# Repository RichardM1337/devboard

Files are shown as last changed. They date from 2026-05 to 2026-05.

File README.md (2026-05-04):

# Devboard
This is my first devboard. It's my introduction to more advanced concepts

This was probably one of the hardest projects I have done ever. The wiring made me want to cry but we were able to get through it. Looking back, I think I've came very far and I'm really happy about my progress.

# PCB
The devboard PCB was made entirely on KiCAD

- Schematic
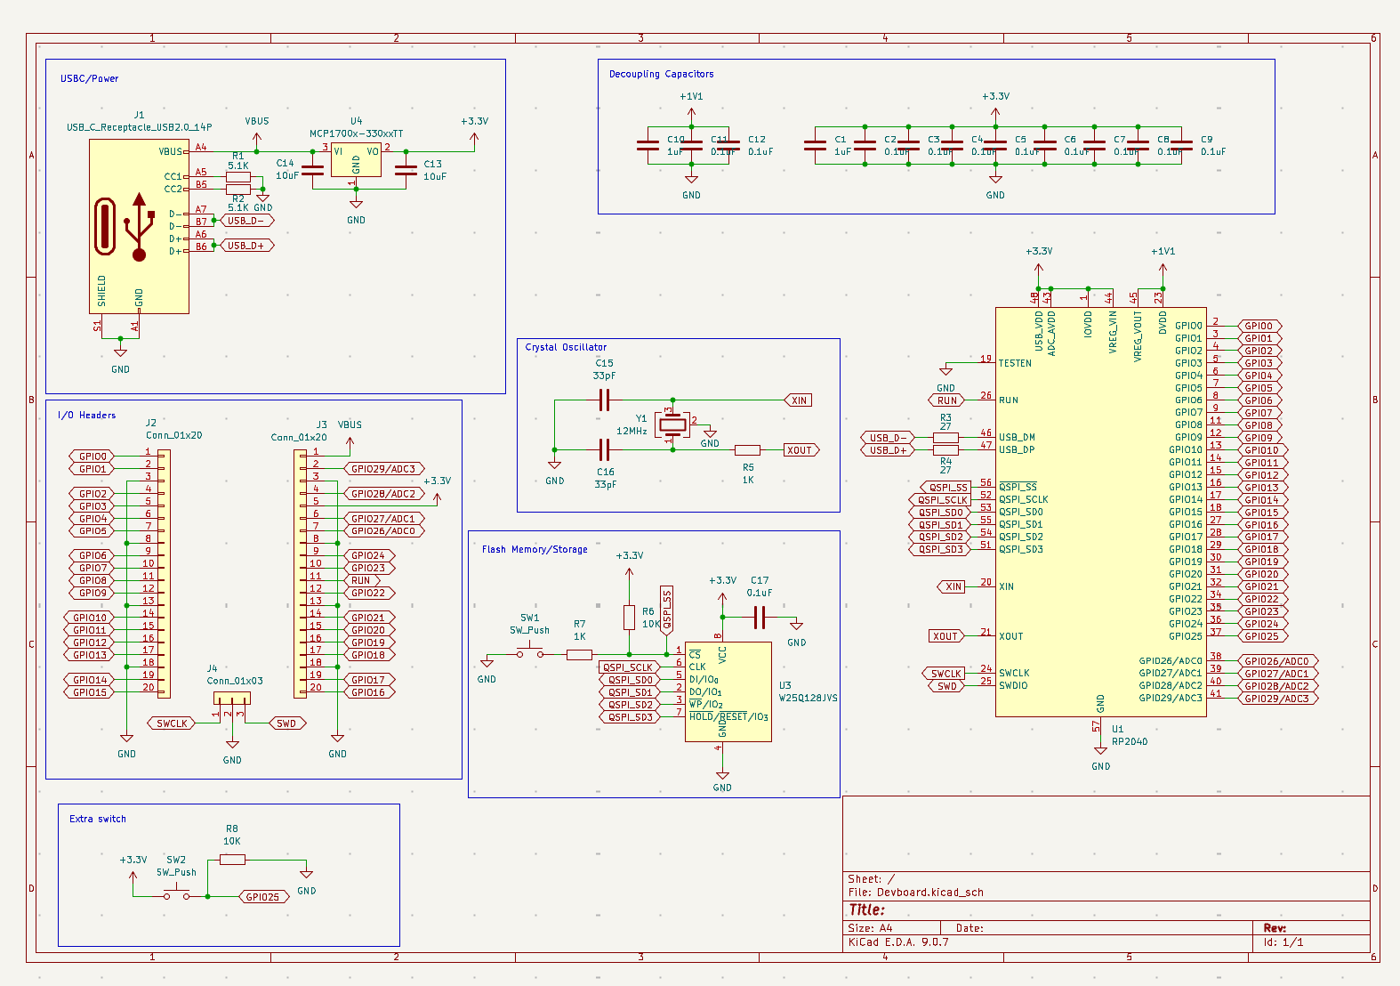
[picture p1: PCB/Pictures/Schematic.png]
Schematic
- 
- PCB Design
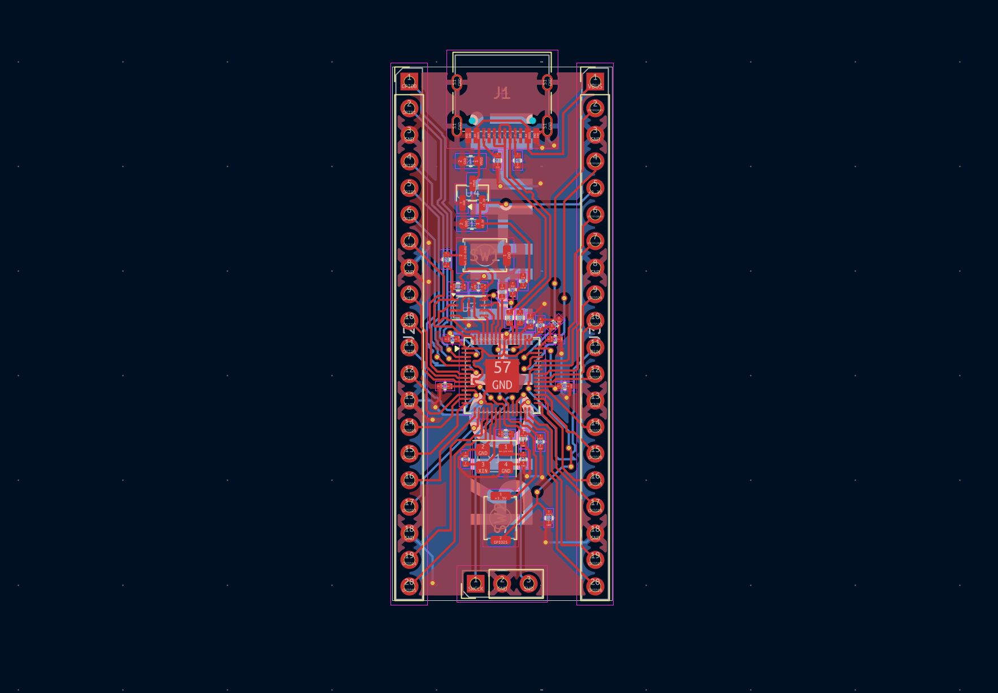
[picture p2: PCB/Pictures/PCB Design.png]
PCB Design
- 

# 3D Model
This 3d model of the devboard was made within the 3d viewer in KiCAD

- Front
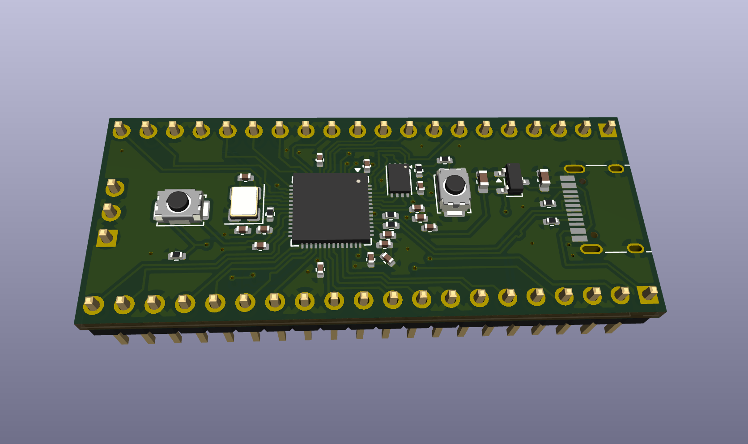
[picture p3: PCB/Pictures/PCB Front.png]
PCB Front
- 
- Back
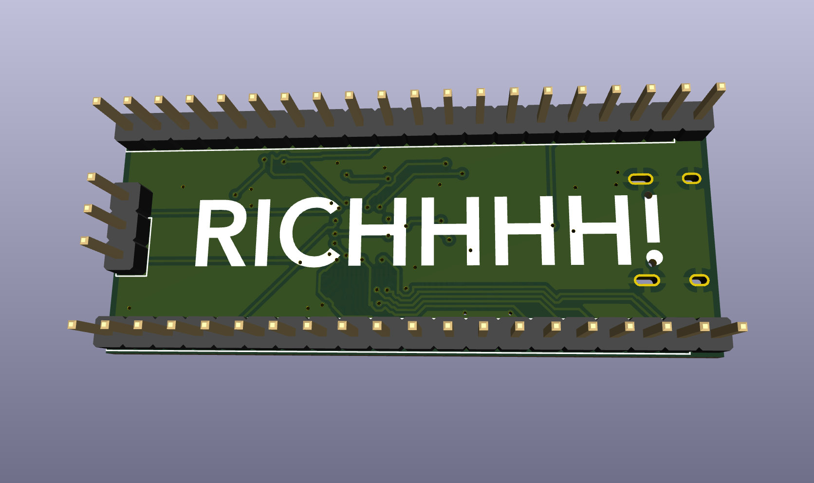
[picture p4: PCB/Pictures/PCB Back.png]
PCB Back
- 

# BOM Bill of Materials

| Quantity | Comment | Designator | Footprint | Link |
|---|---|---|---|---|
| 11 | 0.1uF | C2-9, C11, C12, C17 | C_0402_1005Metric | https://www.lcsc.com/product-detail/C1525.html |
| 2 | 5.1K | R1, R2 | R_0402_1005Metric | https://www.lcsc.com/product-detail/C25905.html |
| 1 | SW_Push | SW1, SW2 | SW_Push_SPST_NO_Alps_SKRK | https://www.lcsc.com/product-detail/C720477.html |
| 2 | 10uF | C13, C14 | C_0603_1608Metric | https://www.lcsc.com/product-detail/C19702.html |
| 2 | 33pF | C15, C16 | C_0402_1005Metric | https://www.lcsc.com/product-detail/C107047.html |
| 2 | 1K | R5, R7 | R_0402_1005Metric | https://www.lcsc.com/product-detail/C11702.html |
| 2 | 10K | R6, R8 | R_0402_1005Metric | https://www.lcsc.com/product-detail/C60490.html |
| 1 | W25Q128JVS | U3 | Winbond_USON-8-1EP_3x2mm_P0.5mm_EP0.2x1.6mm | https://www.lcsc.com/product-detail/C2456208.html  |
| 2 | Conn_01x20 | J2, J3 | PinHeader_1x20_P2.54mm_Vertical | https://www.lcsc.com/product-detail/C42431804.html |
| 1 | Conn_01x03 | J4 | PinHeader_1x03_P2.54mm_Vertical | https://www.lcsc.com/product-detail/C32713269.html |
| 1 | MCP1700x-330xxTT | U4 | SOT-23 | https://www.lcsc.com/product-detail/C39051.html |
| 1 | 12MHz | Y1 | Crystal_SMD_3225-4Pin_3.2x2.5mm | https://www.lcsc.com/product-detail/C9002.html |
| 2 | 27 | R3, R4 | R_0402_1005Metric | https://www.lcsc.com/product-detail/C25100.html |
| 2 | 1uF | C1, C10 | C_0402_1005Metric | https://www.lcsc.com/product-detail/C29266.html |
| 1 | USB_C_Receptacle_USB2.0_14P | J1 | USB_C_Receptacle_HRO_TYPE-C-31-M-12 | https://www.lcsc.com/product-detail/C165948.html |
| 1 | RP2040 | U1 | QFN-56-1EP_7x7mm_P0.4mm_EP3.2x3.2mm | https://www.lcsc.com/product-detail/C2040.html |
| PCBA Estimated Price| $50.84

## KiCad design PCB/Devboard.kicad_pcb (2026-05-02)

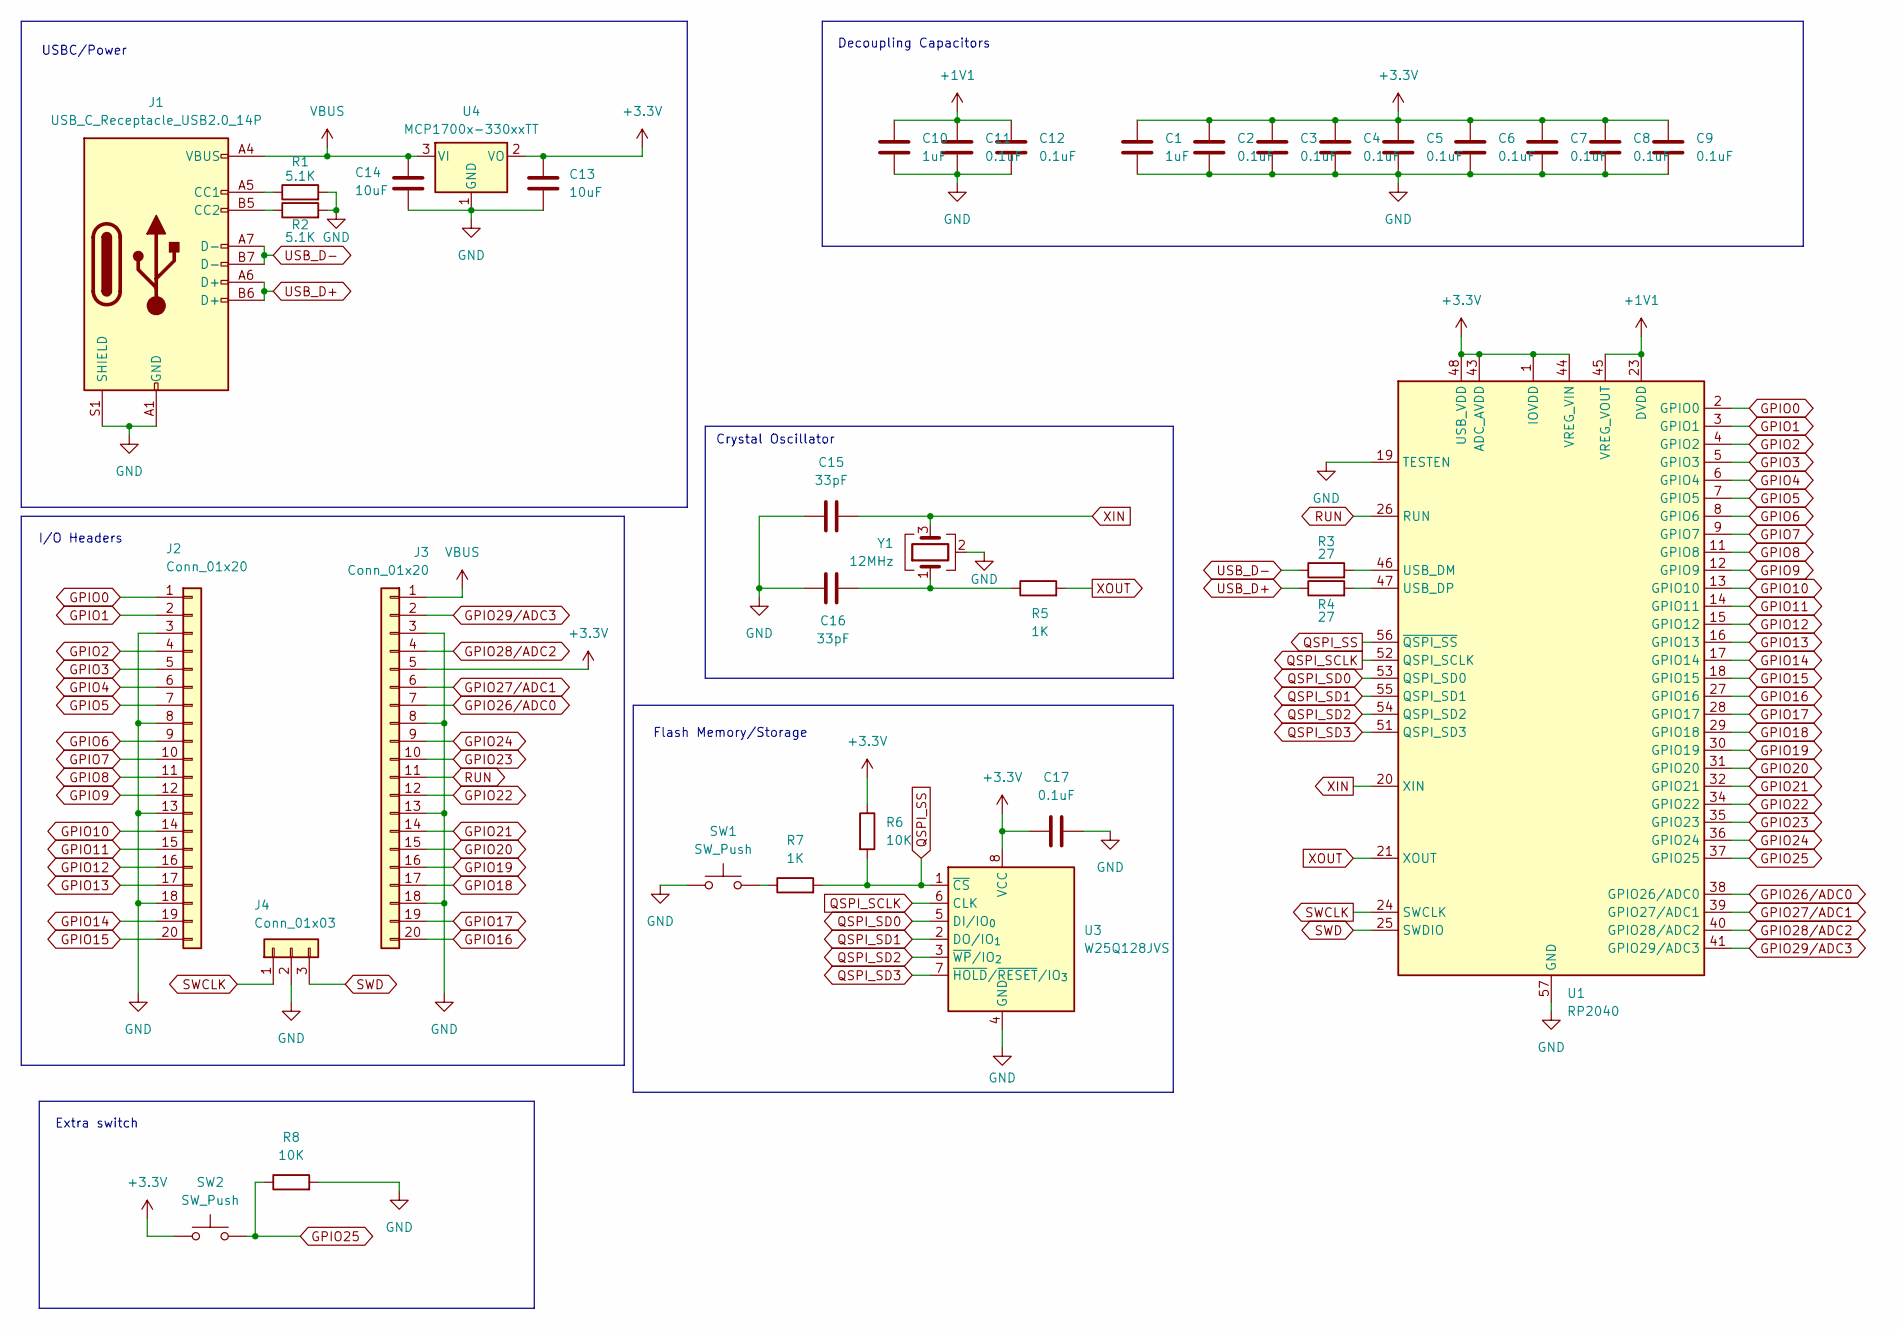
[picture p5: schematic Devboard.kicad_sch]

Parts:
C1, C10: 1uF; C_0402_1005Metric
C2, C3, C4, C5, C6, C7, C8, C9, C11, C12, C17: 0.1uF; C_0402_1005Metric
C13, C14: 10uF; C_0603_1608Metric
C15, C16: 33pF; C_0402_1005Metric
J1: USB_C_Receptacle_USB2.0_14P; USB_C_Receptacle_HRO_TYPE-C-31-M-12
J2, J3: Conn_01x20; PinHeader_1x20_P2.54mm_Vertical
J4: Conn_01x03; PinHeader_1x03_P2.54mm_Vertical
R1, R2: 5.1K; R_0402_1005Metric
R3, R4: 27; R_0402_1005Metric
R5, R7: 1K; R_0402_1005Metric
R6, R8: 10K; R_0402_1005Metric
SW1, SW2: SW_Push; SW_Push_SPST_NO_Alps_SKRK
U1: RP2040; QFN-56-1EP_7x7mm_P0.4mm_EP3.2x3.2mm
U3: W25Q128JVS; Winbond_USON-8-1EP_3x2mm_P0.5mm_EP0.2x1.6mm
U4: MCP1700x-330xxTT; SOT-23
Y1: 12MHz; Crystal_SMD_3225-4Pin_3.2x2.5mm

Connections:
+1V1: C10.1, C11.1, C12.1, U1.23 (DVDD), U1.45 (VREG_VOUT), U1.50 (DVDD)
+3.3V: C1.1, C2.1, C3.1, C4.1, C5.1, C6.1, C7.1, C8.1, C9.1, C13.1, C17.1, J3.5, R6.1, SW2.1, U1.1 (IOVDD), U1.10 (IOVDD), U1.22 (IOVDD), U1.33 (IOVDD), U1.42 (IOVDD), U1.43 (ADC_AVDD), U1.44 (VREG_VIN), U1.48 (USB_VDD), U1.49 (IOVDD), U3.8 (VCC), U4.2 (VO)
GND: C1.2, C2.2, C3.2, C4.2, C5.2, C6.2, C7.2, C8.2, C9.2, C10.2, C11.2, C12.2, C13.2, C14.2, C15.1, C16.1, C17.2, J1.A1 (GND), J1.A12 (GND), J1.B1 (GND), J1.B12 (GND), J1.S1 (SHIELD), J2.3, J2.8, J2.13, J2.18, J3.3, J3.8, J3.13, J3.18, J4.2, R1.2, R2.2, R8.2, SW1.1, U1.19 (TESTEN), U1.57 (GND), U3.4 (GND), U4.1 (GND), Y1.2 (G), Y1.4 (G)
GPIO0: J2.1, U1.2 (GPIO0)
GPIO1: J2.2, U1.3 (GPIO1)
GPIO2: J2.4, U1.4 (GPIO2)
GPIO3: J2.5, U1.5 (GPIO3)
GPIO4: J2.6, U1.6 (GPIO4)
GPIO5: J2.7, U1.7 (GPIO5)
GPIO6: J2.9, U1.8 (GPIO6)
GPIO7: J2.10, U1.9 (GPIO7)
GPIO8: J2.11, U1.11 (GPIO8)
GPIO9: J2.12, U1.12 (GPIO9)
GPIO10: J2.14, U1.13 (GPIO10)
GPIO11: J2.15, U1.14 (GPIO11)
GPIO12: J2.16, U1.15 (GPIO12)
GPIO13: J2.17, U1.16 (GPIO13)
GPIO14: J2.19, U1.17 (GPIO14)
GPIO15: J2.20, U1.18 (GPIO15)
GPIO16: J3.20, U1.27 (GPIO16)
GPIO17: J3.19, U1.28 (GPIO17)
GPIO18: J3.17, U1.29 (GPIO18)
GPIO19: J3.16, U1.30 (GPIO19)
GPIO20: J3.15, U1.31 (GPIO20)
GPIO21: J3.14, U1.32 (GPIO21)
GPIO22: J3.12, U1.34 (GPIO22)
GPIO23: J3.10, U1.35 (GPIO23)
GPIO24: J3.9, U1.36 (GPIO24)
GPIO25: R8.1, SW2.2, U1.37 (GPIO25)
GPIO26/ADC0: J3.7, U1.38 (GPIO26/ADC0)
GPIO27/ADC1: J3.6, U1.39 (GPIO27/ADC1)
GPIO28/ADC2: J3.4, U1.40 (GPIO28/ADC2)
GPIO29/ADC3: J3.2, U1.41 (GPIO29/ADC3)
unnamed: C16.2, R5.1, Y1.1
unnamed: J1.A5 (CC1), R1.1
unnamed: J1.B5 (CC2), R2.1
unnamed: R7.1, SW1.2
unnamed: R3.2, U1.46 (USB_DM)
unnamed: R4.2, U1.47 (USB_DP)
QSPI_SCLK: U1.52 (QSPI_SCLK), U3.6 (CLK)
QSPI_SD0: U1.53 (QSPI_SD0), U3.5 (DI/IO_{0})
QSPI_SD1: U1.55 (QSPI_SD1), U3.2 (DO/IO_{1})
QSPI_SD2: U1.54 (QSPI_SD2), U3.3 (~WP/IO_{2})
QSPI_SD3: U1.51 (QSPI_SD3), U3.7 (~HOLD/~RESET/IO_{3})
QSPI_SS: R6.2, R7.2, U1.56 (~QSPI_SS), U3.1 (~CS)
RUN: J3.11, U1.26 (RUN)
SWCLK: J4.1, U1.24 (SWCLK)
SWD: J4.3, U1.25 (SWDIO)
USB_D+: J1.A6 (D+), J1.B6 (D+), R4.1
USB_D-: J1.A7 (D-), J1.B7 (D-), R3.1
VBUS: C14.1, J1.A4 (VBUS), J1.A9 (VBUS), J1.B4 (VBUS), J1.B9 (VBUS), J3.1, U4.3 (VI)
XIN: C15.2, U1.20 (XIN), Y1.3
XOUT: R5.2, U1.21 (XOUT)

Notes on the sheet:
Flash Memory/Storage
I/O Headers
USBC/Power
Crystal Oscillator
Extra switch
Decoupling Capacitors

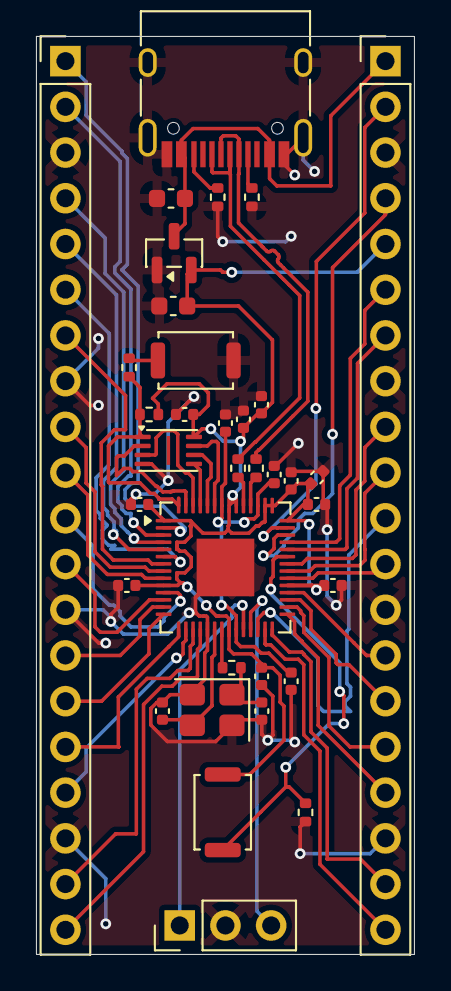
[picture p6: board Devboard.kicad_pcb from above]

Board: 2 copper layers, 21.0 x 51.0 mm, 35 parts (0 on the bottom side), 53 nets.
